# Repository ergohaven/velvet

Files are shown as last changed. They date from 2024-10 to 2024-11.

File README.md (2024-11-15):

## Velvet v3 is a curved, compact mechanical keyboard with a 40% layout size  
*Minimalist, compact, elegant - there is nothing superfluous in it, only the necessary set of elements to know yourself and the harmony of your own world...*

Velvet v3

## Design philosphy
This keyboard [was made](https://www.youtube.com/watch?v=800tXbrIh_E) with FDM printing in mind, the goal was to make a perfect curved case that can be easily printed and looks aesthetically pleasing with minimal amount of so called "steps" that plague similar 3D keyboards like Dactyl Manuform. This is mostly inspired by the Cygnus, Smudge and Chonky Bois keyboards, we wanted to make a similar "organic" shaped keyboard but much more optimized for FDM printing, easy assembly and looking good not only on a photo but also in real life 😎

Velvet v3
Velvet v3

## Features
 
- Ergonomic 3D design
- 46 fully programmable keys, 15 additional layers for all your tasks
- Powered by RP2040 Zero and QMK firmware
- Hotswappable PCB
- Type-C output for connection between halves
- Easily remap any key and customize your keyboard with [Vial](https://get.vial.today/) 
- [Firmware](https://github.com/ergohaven/keymap_hub) is being constantly updated, get the latest QMK features for your keyboard from us ♥️  

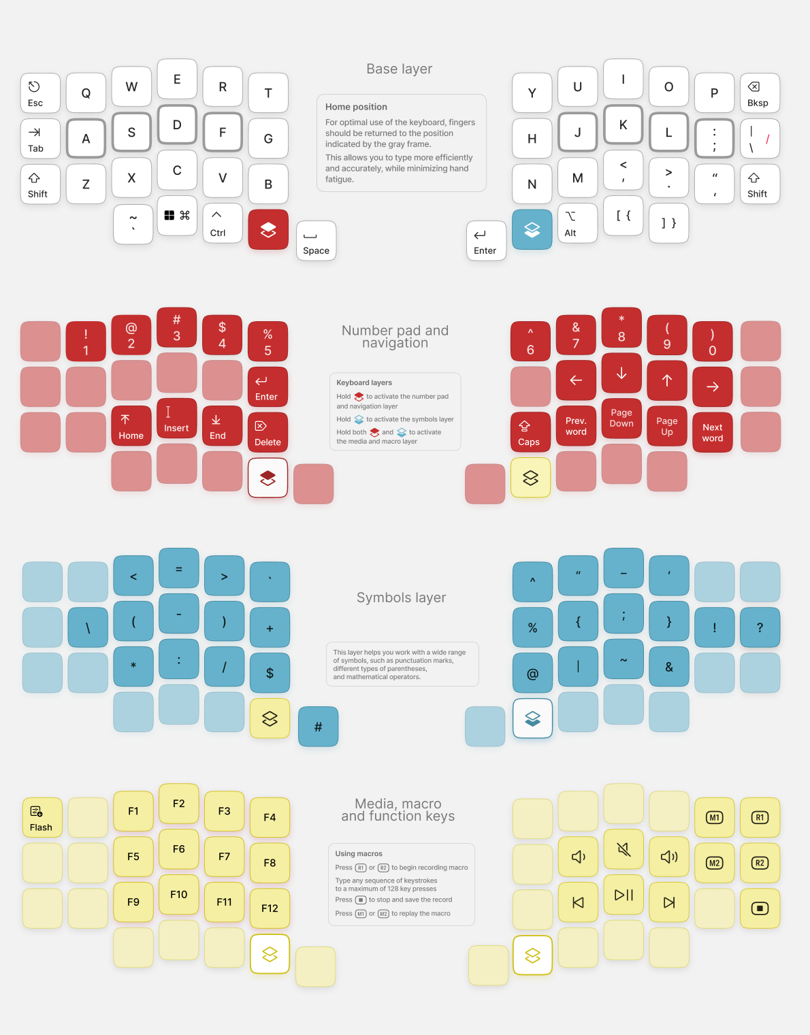
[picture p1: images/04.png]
Velvet v3


## This repo contains all files related to this keyboard
PCB and schematic can be found [here](https://oshwlab.com/yuriiq/velvet_v3)

### Build guide
- [English](https://github.com/ergohaven/velvet/blob/main/build_guide/build_guide_en.md)
- [Russian](https://github.com/ergohaven/velvet/blob/main/build_guide/build_guide_ru.md)

### BOM
- 2 RP2040 Zero MCU 
- 46 MX Hotswap sockets
- 46 1N4148W Diodes (SOD-123)
- 2 Male Pin Header Connector: 11 Pins, 2.54mm, 90 degree [(example)](https://aliexpress.ru/item/1005005614848270.html)
- 2 Female Header Sockets: 11 Pins, 2.54mm, 90 degree [(example)](https://aliexpress.ru/item/1005006067940562.html)
- 4 10kOhm resistors (0805)
- USB Type-C daughterboard: 1.6mm thick [(example)](https://aliexpress.ru/item/1005005857575118.html)
- 30 M2x4 Screws [(example)](https://aliexpress.ru/item/1005005898007060.html)
- 10 M3x4 Inserts [(example)](https://aliexpress.ru/item/1005004290019650.html) 
- 10 M3x4 Screws [(example)](https://aliexpress.ru/item/1005005898007060.html) 
- 1 Type-C to Type-C data cable (for connection between halves)

## License 

The files in this repository are licensed under a Creative Commons Attribution-NonCommercial-ShareAlike 4.0 International License.

## Firmware
- [Pre-compiled files][1]
- [Source code][2]

[1]: https://github.com/ergohaven/keymap_hub
[2]: https://github.com/ergohaven/vial-qmk/tree/vial/keyboards/ergohaven

## Availability
The complete keyboard (not a diy kit!) is available for purchase at [ergohaven.xyz](https://ergohaven.xyz/shop)

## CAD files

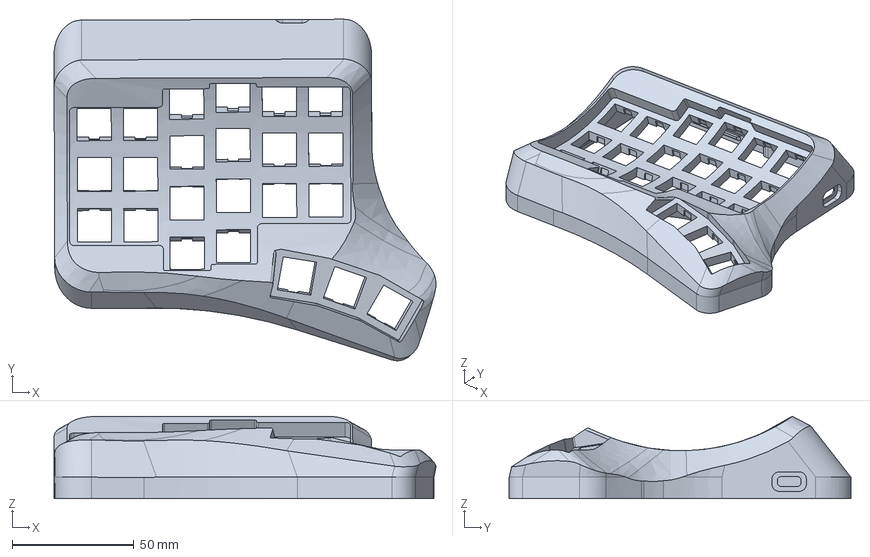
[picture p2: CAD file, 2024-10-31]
step/velvet3-body-left.step
156.8 x 140.2 x 33.8 mm

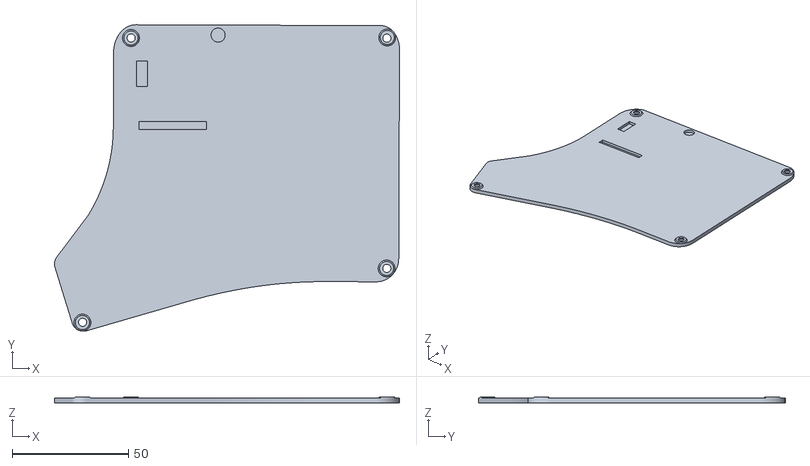
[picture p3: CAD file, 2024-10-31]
stl/velvet-V3-bot-right.stl
148.7 x 132.1 x 2.80

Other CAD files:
step/velvet3-bot-left.step
stl/velvet-V3-bot-left.stl
step/velvet3-bot-right.step
stl/velvet-V3-body-right.stl
step/velvet3-body-right.step
stl/velvet-V3-body-left.stl

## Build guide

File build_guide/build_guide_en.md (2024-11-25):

# Velvet v3 - how to assemble it yourself

## Components:

- Switchplate PCB (FR4, 0.8mm thickness) - 1 pc.
- MCU Holder PCB (FR4 1mm thickness) - 1 pc.
- 3D printed case - 2 pcs. (right and left halves)
- RP2040 Zero MCU - 2 pcs.
- MX Hotswap Sockets - 46 pcs.
- 1N4148W Diodes (SOD-123) - 46 pcs.
- 2 pcs. PLS pin connectors angular, male: 11 Pins, 2.54mm, 90 degree [(example)](https://aliexpress.ru/item/1005005614848270.html)
- 2 pcs. PBS sockets for connectors, female: 11 Pins, 2.54mm, 90 degree [(example)](https://aliexpress.ru/item/1005006067940562.html)
- 4 pcs. 10kOhm resistors (0805)
- USB Type-C mini-plate: 1.6mm thick [(example)](https://aliexpress.ru/item/1005005857575118.html)
- 30 pcs. M2x4 Screw [(example)](https://aliexpress.ru/item/1005005898007060.html)
- 10 pcs. M3x4 Inserts [(example)](https://aliexpress.ru/item/1005004290019650.html)
- 10 pcs. M3x4 Screw [(example)](https://aliexpress.ru/item/1005005898007060.html)
- Type-C to Type-C cable (for connecting halves)
- 3M bumpons/Silicone legs - 8 pcs. [(example)](https://aliexpress.ru/item/32912066603.html)
- MX switches - 46 pcs.
- Key caps - 46 pcs.

## Tools:

- Soldering iron
- Solder (flux-containing)
- Nippers
- Tweezers
- Screwdriver for M3 and M2 screws

## Assembly order

### Preparation of holders

1. Installation of resistors
2. Installation of the microcontroller
3. Installation of Type-C connectors
4. Installation of PBS 11-R connectors
5. Microcontroller firmware

### Preparing the switch plate

1. Applying solder to the pads
2. Installation of hotswap sockets and diodes

### Assembly into housing

1. Installation of switches
2. Installation of switchplate and brass inserts
3. Installation of the holder
4. Keyboard check
5. Installation of the lower plate

### Preparation of holders

#### Installing resistors

First you need to prepare the board for the holder. We install resistors on both halves of the holder.
On the right half - on the R3 platform, on the left - on R2.



#### Installing the microcontroller

Do not mix up the installation side. We place the microcontroller level and first solder pins 13 and 0 to fix it on the board. After we have fixed the microcontroller smoothly, we solder the remaining contacts.





#### Installing Type-C connectors

We place the Type-C connector on the holder and solder one contact on the back side to fix the PLS 4pin connector, as shown in Fig. 1.
Then, on the other side, we also solder one Type-C contact with a PLS connector, as shown in Fig. 2. Next, we add PLS, as shown in Fig. 3.
Then we cut off the extra legs with wire cutters and solder the Type-C connector.






#### Installing corner sockets

Next, we solder both PBS 11-R connectors and also cut off the legs on the reverse side with pliers so that they do not interfere with us placing the board in the case.




#### Microcontroller firmware

After we have finished soldering the holders, we need to flash them:
- Connect the microcontroller to the PC
- The microcontroller must be identified as a USB drive
- Drag and drop [firmware file](https://github.com/ergohaven/keymap_hub/) onto it
- The microcontroller is flashed

If your RP2040-Zero is not detected as a drive, then you need to
Hold down the Boot key on it and connect USB. Then repeat the steps of dragging the Uf2 firmware file.

### Preparing the switch plate

#### Applying solder to pads

First you need to prepare the board. To do this, we apply solder to the pads on one side of the component to make it easier to solder.



#### Installing hotswap sockets and diodes

Diodes have polarity and therefore it is important to install them with the correct side. The cathode is marked with a white line on the diode. The boards also have a silkscreen with the same line. We solder “line to line”.
All diodes must be installed in the same direction

Next, you need to install hotswap sockets into the hole and solder them.




### Assembly into housing

#### Setting switches

First you need to install the switches into the case, as shown in the figure.

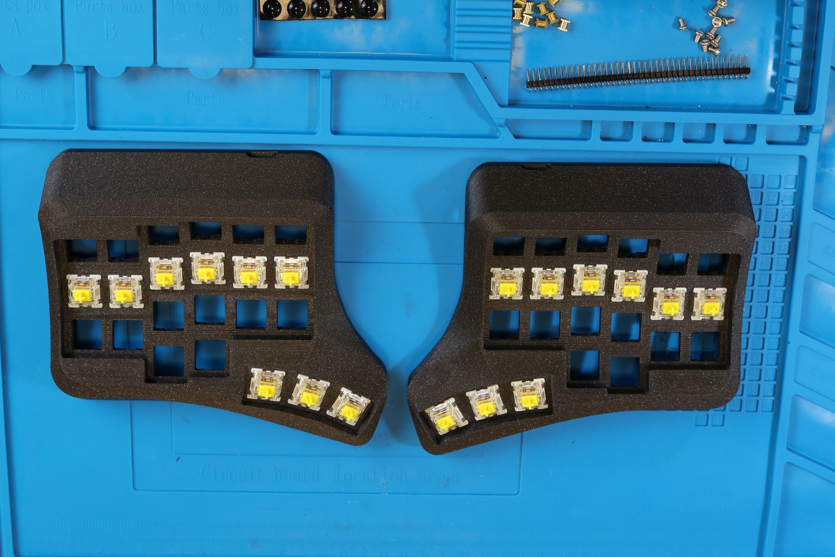
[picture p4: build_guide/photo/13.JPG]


#### Installing the switchplate and brass inserts

We attach it to the switches of the right half (we do not attach the tambo cluster yet) and tighten two M2x4mm screws, as shown in the figure.


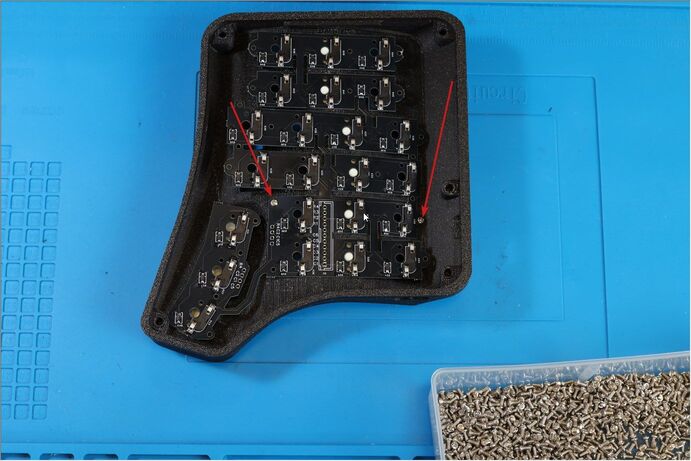
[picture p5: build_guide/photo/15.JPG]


Then we fix the tamb cluster and tighten five M2x4 mm screws, as shown in the figure.

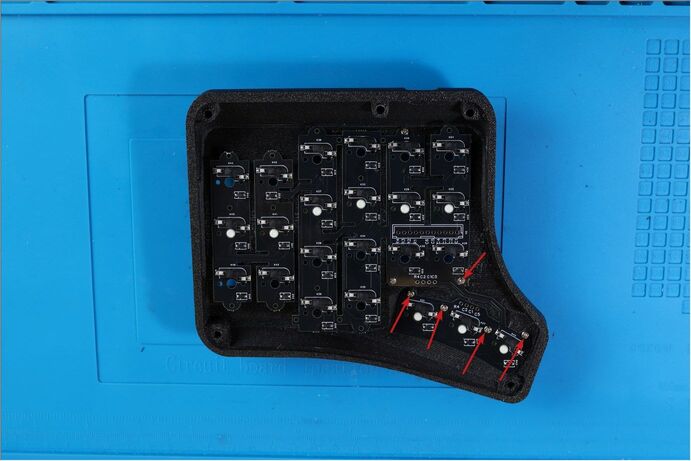
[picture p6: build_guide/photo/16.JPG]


Then we tighten the remaining screws and install five M3x5mm brass inserts with a heated soldering iron around the perimeter of the case, as shown in the figure below



The finished result should look like the picture

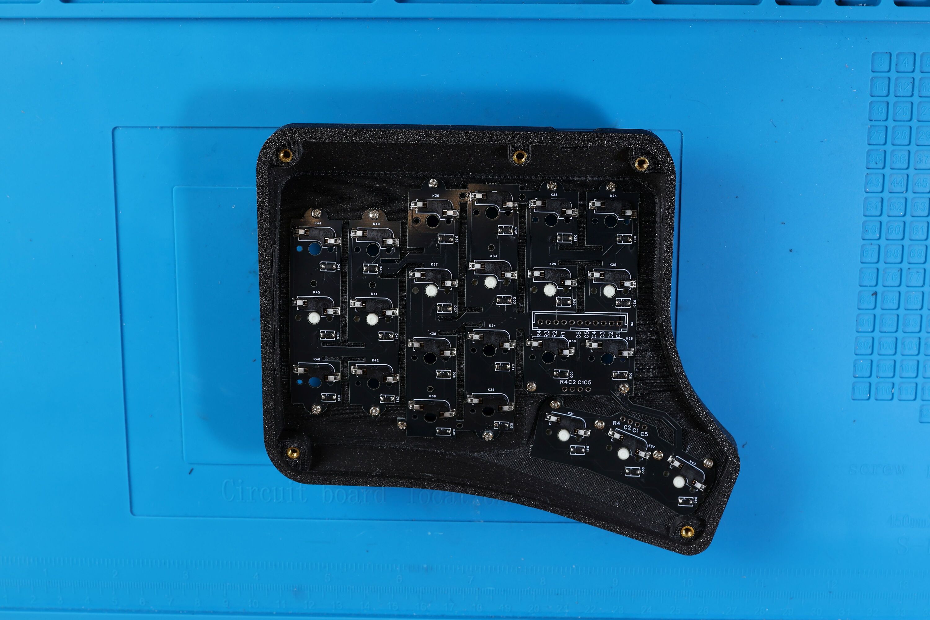
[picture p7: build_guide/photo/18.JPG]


#### Installation of the holder

Take PLS 11-R and insert it into the connector on the holder, as shown in the figure



We install the holder and tighten the M3x4mm screw, as shown in the figure.

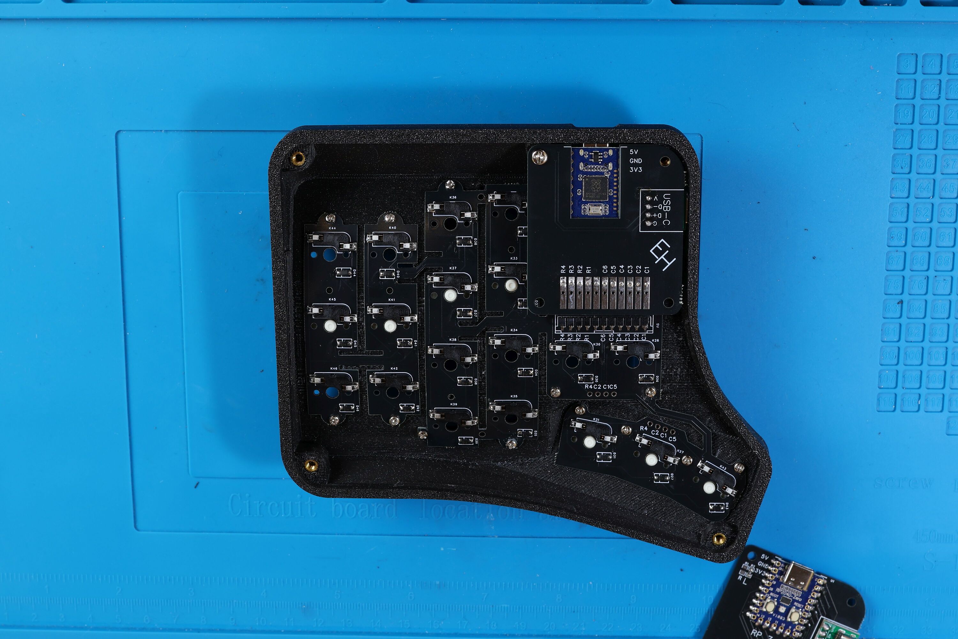
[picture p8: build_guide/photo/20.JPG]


Next, pressing the holder all the way, solder each pin of the PLS connector to the switchplate.



We assemble the left half in the same way.

#### Keyboard check

After we have assembled both halves, we install all the switches, connect them to each other with a Type-C cable and connect the keyboard to the PC

Next, we will need to check the keyboard:
- Go to [Vial](https://get.vial.today/download/)
- Click on the “Matrix tester” menu, then “Unlock” and follow the instructions on the screen to unlock the keyboard
- We check every key

If all the keys work correctly, then we begin to tighten the lower plates

#### Installing the bottom plate

We place the plate into the case and tighten it with M3x4mm screws, then install silicone feet to hide the screws

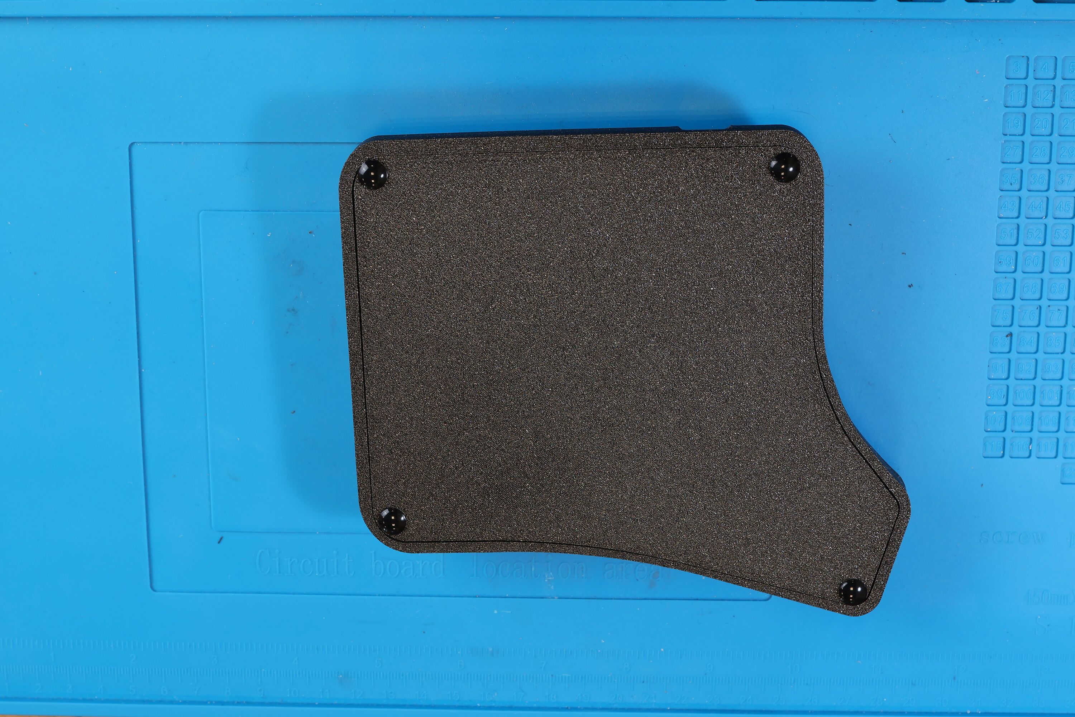
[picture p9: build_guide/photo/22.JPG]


Install your favorite keycaps and enjoy your new keyboard!



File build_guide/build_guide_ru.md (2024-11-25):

# Velvet v3 - как его собрать самостоятельно

## Компоненты:  

- Свитчплейт плата (FR4, 0.8мм толщина) - 1 шт. 
- Плата холдера контроллера (FR4, 1мм толщина) - 1 шт.
- 3D корпус - 1 шт. (правая и левая половинки)
- RP2040 Zero микроконтроллер - 2 шт. 
- MX Хотсвап Сокеты - 46 шт.
- 1N4148W Диоды (SOD-123) - 46 шт.
- 2 шт. PLS пин коннекторы угловые, папа : 11 пинов, 2.54мм, угловые [(пример)](https://aliexpress.ru/item/1005005614848270.html)
- 2 шт. PBS сокеты для коннекторов, мама: 11 пинов, 2.54мм, угловые [(пример)](https://aliexpress.ru/item/1005006067940562.html)
- 4 шт. 10kOhm резисторы (0805)
- USB Type-C мини-плата: 1.6мм толщина [(пример)](https://aliexpress.ru/item/1005005857575118.html)
- 30 шт. M2x4 Винт [(пример)](https://aliexpress.ru/item/1005005898007060.html)
- 10 шт. M3x4 Инсерты [(пример)](https://aliexpress.ru/item/1005004290019650.html) 
- 10 шт. M3x4 Винт [(пример)](https://aliexpress.ru/item/1005005898007060.html) 
- 1 шт. Type-C к Type-C кабель (для соединения половинок)
- 3M бампоны/Силиконовые ножки - 8 шт. [(пример)](https://aliexpress.ru/item/32912066603.html)
- Свитчи МХ - 46 шт.
- Кейкапы - 46 шт.

## Инструменты: 

- Паяльник
- Припой (флюсосодержащий)
- Кусачки
- Пинцет
- Отвёртка для винтов M3 и M2

## Порядок сборки

### Подготовка холдера 

1. Установка резисторов
2. Установка микроконтроллера
3. Установка Type-C коннекторов
4. Установка PBS 11-R коннекторов
5. Прошивка микроконтроллера

### Подготовка свитч плейта 

1. Нанесение припоя на контактные площадки
2. Установка хотсвап сокетов и диодов

### Сборка в корпус

1. Установка переключателей
2. Установка свитчплейта и латунных вставок
3. Установка холдера
4. Проверка клавиатуры
5. Установка нижнего плейта

### Подготовка холдера 

#### Установка резисторов

Для начала необходимо подготовить плату для холдера. Устанавливаем резисторы на обе половинки холдера. 
На правой половинке — на площадку R3, на левой — на R2.



#### Установка микроконтроллера

Не перепутайте сторону установки. Ставим ровно микроконтроллер и сначала запаиваем 13 и 0 пины, чтобы его зафиксировать на плате. После того, как мы ровно зафиксировали микроконтроллер - запаиваем остальные контакты. 





#### Установка Type-C коннекторов

Размещаем Type-C коннектор на холдере и запаиваем с обратной стороны один контакт, чтобы зафиксировать PLS 4pin коннектор, как показано на рис. 1.
Затем с другой стороны запаиваем также один контакт Type-C с PLS коннектором, как показано на рис.2. Далее допаиваем PLS, как показано на рис. 3.
После обрезаем лишние ножки кусачками и допаиваем Type-C коннектор.






#### Установка угловых сокетов 

Далее запаиваем оба PBS 11-R коннектора и также обрезаем кусачками ножки с обратной стороны, чтобы они не мешали нам для размещения платы в корпусе.




#### Прошивка микроконтроллера

После того, как мы закончили с пайкой холдеров, необходимо их прошить: 
- Подключаем микроконтроллер к ПК
- Микроконтроллер должен определиться как USB накопитель  
- Перетаскиваем на него [файл прошивки](https://github.com/ergohaven/keymap_hub/)  
- Микроконтроллер прошит  

Если у вас RP2040-Zero не определился как накопитель, то необходимо 
зажать на нём клавишу Boot и подключить USB. Затем повторить действия с перетаскивание Uf2 файла прошивки.

### Подготовка свитч плейта

####  Нанесение припоя на контактные площадки 

Для начала необходимо подготовить плату. Для этого наносим припой на контактные площадки с одной стороны компонента, чтобы его было легче припаивать.



#### Установка хотсвап сокетов и диодов

Диоды имеют полярность и поэтому важно устанавливать их правильной стороной. Катод отмечен белой линией на диоде. На платах также имеется шёлкография с такой же линией. Паяем «линия к линии».
Все диоды должны быть установлены в одном направлении

Далее необходимо установить в отверстие хотсвап сокеты и запаять.




### Сборка в корпус

#### Установка переключателей

Для начала необходимо установить свитчи в корпус, как показано на рисунке 



#### Устанавливаем свитчплейт и латунные вставки

Закрепляем его на свитчи правой половинки (тамб-кластер пока не закрепляем) и закручиваем два винта М2х4мм, как показано на рисунке.




Затем закрепляем тамб-кластер и закручиваем пять винтов М2х4 мм., как показано на рисунке.



После закручиваем остальные винты и устанавливаем пять латунных вставок М3х5мм разогретым паяльником по периметру корпуса, как показано на рисунке ниже



Готовый результат должен выглядеть как на рисунке



#### Установка холдера 

Берём PLS 11-R и вставляем в коннектор на холдере, как показано на рисунке 



Устанавливаем холдер и закручиваем М3х4мм винт, как показано ни рисунке. 



Далее, придавливая холдер до упора, запаиваем каждый пин PLS разъёма на свитчплейт. 



Левую половинку собираем аналогично.

#### Проверка клавиатуры

После того, как мы собрали обе половинки, устанавливаем все свитчи, соединяем их между собой Type-C кабелем и подключаем клавитуру к ПК

Далее, нам необходимо будет проверить клавиатуру:  
- Заходим в [Vial](https://get.vial.today/download/)  
- Кликаем на меню “Matrix tester”, дальше “Unlock” и следуем инструкции на экране для разблокировки клавиатуры  
- Проверяем каждую клавишу

Если все клавиши работают корректно, то начинаем закручивать нижние плейты

#### Установка нижнего плейта

Помещаем плейт в корпус и закручиваем его М3х4мм винтами, затем устанавливаем силиконовые ножки, чтобы скрыть винты



Установите Ваши любимые кейкапы и наслаждайтесь удобством и эргономикой!



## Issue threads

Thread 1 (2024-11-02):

Can you upload the pcb files to github ?

Testiclo, 2024-11-02:
I can't download them from oshlab , because I'm blocked (I don't know why )

kissetfall, 2024-11-15:
Hi, I have added gerbers, chech the releases section.

Closed 2024-11-15.
